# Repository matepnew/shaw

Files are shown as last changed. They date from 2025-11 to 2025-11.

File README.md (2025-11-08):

# SHAW!
Devboard based on the Blueprint guides to learn basics of electronics and PCB design.
 
## PCB
### Schematic


### PCB layout




### 3D Model




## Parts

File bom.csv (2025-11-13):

JLCPCB BOM Tool - BOM Matching
BOM name：bom-JLCPCB Assembly Order.xlsx |  |  | Download Time：2025-11-14 07:38:49 |  |  |  | * Our matching results are updated in real-time, but stock and prices may change. If it's been over 24 hours, please re-match before placing your order.
PCB Assembled Qty：5 |  |  | Est. Total Price：17.9448
Your BOM |  |  |  |  | Matched Parts |  |  |  |  |  |  | Order Information
Top Designator | Bottom Designator | Comment | Footprint | JLCPCB Part # | Matches | Part # | Manufacturer | Footprint | Description | Category | Warning | JLCPCB Part # | Product link | Lib Type | Qty | Source | Total Price ($)
C1,C12,C18 |  | 1uF | 0402 |  | Select by System | CL05A105KA5NQNC | Samsung Electro-Mechanics | 0402 | 1uF 25V X5R ±10% 0402 Multilayer Ceramic Capacitors MLCC - SMD/SMT ROHS | Multilayer Ceramic Capacitors MLCC - SMD/SMT |  | C52923 | https://jlcpcb.com/partdetail/53938-CL05A105KA5NQNC/C52923 | Basic | 15 | 15 JLCPCB | 0.0435
C10,C11,C17,C2,C3,C4,C5,C6,C7,C8,C9 |  | 0.1uF | 0402 |  | Unconfirmed | CL05B104KB54PNC | Samsung Electro-Mechanics | 0402 | 100nF 50V X7R ±10% 0402 Multilayer Ceramic Capacitors MLCC - SMD/SMT ROHS | Multilayer Ceramic Capacitors MLCC - SMD/SMT | 1.The comment (CL05B104KB54PNC) of this part does not match the one (0.1uF) provided in your BOM. Please confirm; | C307331 | https://jlcpcb.com/partdetail/291005-CL05B104KB54PNC/C307331 | Basic | 55 | 55 JLCPCB | 0.1925
C13,C14 |  | 10uF | 0603 |  | Select by System | CL10A106KP8NNNC | Samsung Electro-Mechanics | 0603 | 10V 10uF X5R ±10% 0603 Multilayer Ceramic Capacitors MLCC - SMD/SMT ROHS | Multilayer Ceramic Capacitors MLCC - SMD/SMT |  | C19702 | https://jlcpcb.com/partdetail/20411-CL10A106KP8NNNC/C19702 | Basic | 10 | 10 JLCPCB | 0.056
C15,C16 |  | 33pF | 0402 |  | Select by System | 0402CG330J500NT | FH (Guangdong Fenghua Advanced Tech) | 0402 | 33pF 50V C0G ±5% 0402 Multilayer Ceramic Capacitors MLCC - SMD/SMT ROHS | Multilayer Ceramic Capacitors MLCC - SMD/SMT |  | C1562 | https://jlcpcb.com/partdetail/1914-0402CG330J500NT/C1562 | Basic | 10 | 10 JLCPCB | 0.01
C19,C20 |  | 4.7uF | 0603 |  | Select by System | CL10A475KO8NNNC | Samsung Electro-Mechanics | 0603 | 16V 4.7uF X5R ±10% 0603 Multilayer Ceramic Capacitors MLCC - SMD/SMT ROHS | Multilayer Ceramic Capacitors MLCC - SMD/SMT |  | C19666 | https://jlcpcb.com/partdetail/20375-CL10A475KO8NNNC/C19666 | Basic | 10 | 10 JLCPCB | 0.092
D1,D2 |  | LED | 0402 |  | Unconfirmed | XL-1005UGC | XINGLIGHT | 0402 | -40℃~+85℃ 120° 249mcd 25mA 3V 516nm~531nm 531nm 80mW Emerald Green Water Clear op View Mount 0402 LED Indication - Discrete ROHS | LED Indication - Discrete | 1.The comment (XL-1005UGC) of this part does not match the one (LED) provided in your BOM. Please confirm; | C965793 | https://jlcpcb.com/partdetail/XINGLIGHT-XL1005UGC/C965793 | Extended | 22 | 22 JLCPCB | 0.1474
J1 |  | USB_C_Receptacle_USB2.0_14P | USB_C_Receptacle_HRO_TYPE-C-31-M-12 |  | Select by Customer | TYPE-C-31-M-12 | Korean Hroparts Elec | SMD | 1 16P 5A Female Type-C SMD USB Connectors ROHS | USB Connectors |  | C165948 | https://jlcpcb.com/partdetail/Korean_HropartsElec-TYPE_C_31_M12/C165948 | Extended | 5 | 5 JLCPCB | 0.847
J2,J3 |  | Conn_01x20 | PinHeader_1x20_P2.54mm_Vertical |  | Select by Customer | 2.54-1*20P直针 | BOOMELE(Boom Precision Elec) | 插件,P=2.54mm | -40℃~+105℃ 1 1x20P 2.54mm 20P 3A Black Brass Pin Header Through Hole Plugin,P=2.54mm Pin Headers ROHS | Pin Headers |  | C50981 | https://jlcpcb.com/partdetail/51993-2_54_1_20P/C50981 | Extended | 0 | 0 JLCPCB | 0
J4 |  | Conn_01x03 | PinHeader_1x03_P2.54mm_Vertical |  | Select by Customer | 2.54-1*3P针 | BOOMELE(Boom Precision Elec) | 插件,P=2.54mm | -40℃~+105℃ 1 1x3P 2.54mm 2.5mm 3A 3P 3mm 6mm Black Brass Gold Pin Header Through Hole Plugin,P=2.54mm Pin Headers ROHS | Pin Headers |  | C49257 | https://jlcpcb.com/partdetail/50265-2_54_1_3P/C49257 | Extended | 0 | 0 JLCPCB | 0
J5 |  | Conn_01x02 | JST_EH_B2B-EH-A_1x02_P2.50mm_Vertical |  | Select by Customer | B2B-EH-A(LF)(SN) | JST | 插件,P=2.5mm | -25℃~+85℃ 1 1x2P 2 2.5mm 250V 2P 3.8mm 3A 6mm 7.5mm Brass EH PA66 Through Hole Tin UL94V-0 White Plugin,P=2.5mm Wire To Board Connector ROHS | Wire To Board Connector |  | C160262 | https://jlcpcb.com/partdetail/JST-B2B_EH_A_LF_SN/C160262 | Extended | 9 | 9 JLCPCB | 0.3177
R1,R2 |  | 5.1K | 0402 |  | Unconfirmed | 0402WGF5101TCE | UNI-ROYAL(Uniroyal Elec) | 0402 | -55℃~+155℃ 5.1kΩ 50V 62.5mW Thick Film Resistor ±1% ±100ppm/℃ 0402 Chip Resistor - Surface Mount ROHS | Chip Resistor - Surface Mount | 1.The comment (0402WGF5101TCE) of this part does not match the one (5.1K) provided in your BOM. Please confirm; | C25905 | https://jlcpcb.com/partdetail/26648-0402WGF5101TCE/C25905 | Basic | 10 | 10 JLCPCB | 0.005
R3,R4 |  | 27 | 0402 |  | Unconfirmed | 0402WGF270JTCE | UNI-ROYAL(Uniroyal Elec) | 0402 | -55℃~+155℃ 27Ω 50V 62.5mW Thick Film Resistor ±1% ±100ppm/℃ 0402 Chip Resistor - Surface Mount ROHS | Chip Resistor - Surface Mount | 1.The comment (0402WGF270JTCE) of this part does not match the one (27) provided in your BOM. Please confirm; | C25100 | https://jlcpcb.com/partdetail/25843-0402WGF270JTCE/C25100 | Extended | 22 | 22 JLCPCB | 0.0132
R5,R7 |  | 1K | 0402 |  | Unconfirmed | 0402WGF1001TCE | UNI-ROYAL(Uniroyal Elec) | 0402 | -55℃~+155℃ 1kΩ 50V 62.5mW Thick Film Resistor ±1% ±100ppm/℃ 0402 Chip Resistor - Surface Mount ROHS | Chip Resistor - Surface Mount | 1.The comment (0402WGF1001TCE) of this part does not match the one (1K) provided in your BOM. Please confirm; | C11702 | https://jlcpcb.com/partdetail/12256-0402WGF1001TCE/C11702 | Basic | 10 | 10 JLCPCB | 0.006
R8,R9 |  | 1.5K | 0402 |  | Unconfirmed | 0402WGF1501TCE | UNI-ROYAL(Uniroyal Elec) | 0402 | -55℃~+155℃ 1.5kΩ 50V 62.5mW Thick Film Resistor ±1% ±100ppm/℃ 0402 Chip Resistor - Surface Mount ROHS | Chip Resistor - Surface Mount | 1.The comment (0402WGF1501TCE) of this part does not match the one (1.5K) provided in your BOM. Please confirm; | C25867 | https://jlcpcb.com/partdetail/26610-0402WGF1501TCE/C25867 | Basic | 10 | 10 JLCPCB | 0.006
R10 |  | 4.12K | 0402 |  | Unconfirmed | RC0402FR-074K12L | YAGEO | 0402 | -55℃~+155℃ 4.12kΩ 50V 62.5mW Thick Film Resistor ±1% ±100ppm/℃ 0402 Chip Resistor - Surface Mount ROHS | Chip Resistor - Surface Mount | 1.The comment (RC0402FR-074K12L) of this part does not match the one (4.12K) provided in your BOM. Please confirm; | C327340 | https://jlcpcb.com/partdetail/YAGEO-RC0402FR074K12L/C327340 | Extended | 20 | 20 JLCPCB | 0.006
R11 |  | 1.18K | 0402 |  | Unconfirmed | 0402WGF1181TCE | UNI-ROYAL(Uniroyal Elec) | 0402 | -55℃~+155℃ 1.18kΩ 50V 62.5mW Thick Film Resistor ±1% ±100ppm/℃ 0402 Chip Resistor - Surface Mount ROHS | Chip Resistor - Surface Mount | 1.The comment (0402WGF1181TCE) of this part does not match the one (1.18K) provided in your BOM. Please confirm; | C270651 | https://jlcpcb.com/partdetail/260031-0402WGF1181TCE/C270651 | Extended | 20 | 20 JLCPCB | 0.008
R12 |  | 1.13K | 0402 |  | Unconfirmed | 0402WGF1131TCE | UNI-ROYAL(Uniroyal Elec) | 0402 | -55℃~+155℃ 1.13kΩ 50V 62.5mW Thick Film Resistor ±1% ±100ppm/℃ 0402 Chip Resistor - Surface Mount ROHS | Chip Resistor - Surface Mount | 1.The comment (0402WGF1131TCE) of this part does not match the one (1.13K) provided in your BOM. Please confirm; | C67014 | https://jlcpcb.com/partdetail/68102-0402WGF1131TCE/C67014 | Extended | 20 | 20 JLCPCB | 0.012
R13,R6 |  | 10K | 0402 |  | Unconfirmed | 0402WGF1002TCE | UNI-ROYAL(Uniroyal Elec) | 0402 | -55℃~+155℃ 10kΩ 50V 62.5mW Thick Film Resistor ±1% ±100ppm/℃ 0402 Chip Resistor - Surface Mount ROHS | Chip Resistor - Surface Mount | 1.The comment (0402WGF1002TCE) of this part does not match the one (10K) provided in your BOM. Please confirm; | C25744 | https://jlcpcb.com/partdetail/26487-0402WGF1002TCE/C25744 | Basic | 10 | 10 JLCPCB | 0.006
SW1 |  | SW_Push | SW_Push_SPST_NO_Alps_SKRK |  | Select by Customer | TS-1088-AR02016 | XUNPU | SMD,4x3mm | -30℃~+80℃ 1.6N 100,000 Cycles 12V 2mm 3mm 4mm 50mA Black Round Button SMD(SMT) Tab SPST Surface Mount,Vertical Without Bracket SMD,4x3mm Tactile Switches ROHS | Tactile Switches |  | C720477 | https://jlcpcb.com/partdetail/XUNPU-TS_1088AR02016/C720477 | Basic | 5 | 5 JLCPCB | 0.2125
U1 |  | RP2040 | QFN-56-1EP_7x7mm_P0.4mm_EP3.2x3.2mm |  | Select by Customer | RP2040 | Raspberry Pi | LQFN-56(7x7) | 12bit 133MHz 30 LQFN-56(7x7) Microcontrollers (MCU/MPU/SOC) ROHS | Microcontrollers (MCU/MPU/SOC) |  | C2040 | https://jlcpcb.com/partdetail/RaspberryPi-RP2040/C2040 | Extended | 5 | 5 JLCPCB | 4.5825
U2 |  | MCP1700x-330xxTT | SOT-23 |  | Select by Customer | 2SA812(RANGE:300-400) | Jiangsu Changjing Electronics Technology Co., Ltd. | SOT-23 | -55℃~+150℃ 1 PNP 100mA 100nA 180MHz 200mW 300mV@100mA,10mA 50V 5V 90@1mA,6V PNP SOT-23 Bipolar (BJT) ROHS | Bipolar (BJT) |  | C2132 | https://jlcpcb.com/partdetail/2489-2SA812_RANGE_300_400/C2132 | Extended | 10 | 10 JLCPCB | 0.139
U3 |  | W25Q16JVSS | Winbond_USON-8-1EP_3x2mm_P0.5mm_EP0.2x1.6mm |  | Select by Customer | W25Q16JVUXIQ | Winbond Elec | USON-8-EP(2x3) | 100,000 Cycles 133MHz 16Mbit 2.7V~3.6V 20 Years 3ms SPI USON-8-EP(2x3) NOR FLASH ROHS | NOR FLASH | 1.The comment (W25Q16JVUXIQ) of this part does not match the one (W25Q16JVSS) provided in your BOM. Please confirm; | C2843335 | https://jlcpcb.com/partdetail/WinbondElec-W25Q16JVUXIQ/C2843335 | Extended | 5 | 5 JLCPCB | 3.2625
U4 |  | BQ24074RGT | VQFN-16-1EP_3x3mm_P0.5mm_EP1.6x1.6mm |  | Select by Customer | BQ24074RGTR | Texas Instruments | QFN-16-EP(3x3) | -40℃~+125℃ 1 1.5A 4.2V 4.35V~10.2V 6.5uA Charging IC Lithium Battery Support QFN-16-EP(3x3) Battery Management ROHS | Battery Management | 1.The comment (BQ24074RGTR) of this part does not match the one (BQ24074RGT) provided in your BOM. Please confirm; | C54313 | https://jlcpcb.com/partdetail/TexasInstruments-BQ24074RGTR/C54313 | Extended | 5 | 5 JLCPCB | 6.0075
Y1 |  | 12MHz | Crystal_SMD_3225-4Pin_3.2x2.5mm |  | Unconfirmed | DSX321G 12MHz | KDS Daishinku | SMD3225-4P | SMD3225-4P Crystals ROHS | Crystals | 1.The comment (DSX321G 12MHz) of this part does not match the one (12MHz) provided in your BOM. Please confirm; | C93234 | https://jlcpcb.com/partdetail/KDSDaishinku-DSX321G12MHz/C93234 | Extended | 5 | 5 JLCPCB | 1.9725

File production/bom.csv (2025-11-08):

Designator | Footprint | Quantity | Value | LCSC Part #
C1, C12, C18 | 0402 | 3 | 1uF
C10, C11, C17, C2, C3, C4, C5, C6, C7, C8, C9 | 0402 | 11 | 0.1uF
C13, C14 | 0603 | 2 | 10uF
C15, C16 | 0402 | 2 | 33pF
C19 | 0603 | 1 | 4.7uF
C20 | 0201 | 1 | 4.7uF
D1, D2 | 0402 | 2 | LED
J1 | USB_C_Receptacle_HRO_TYPE-C-31-M-12 | 1 | USB_C_Receptacle_USB2.0_14P
J2, J3 | PinHeader_1x20_P2.54mm_Vertical | 2 | Conn_01x20
J4 | PinHeader_1x03_P2.54mm_Vertical | 1 | Conn_01x03
J5 | JST_EH_B2B-EH-A_1x02_P2.50mm_Vertical | 1 | Conn_01x02
R1, R2 | 0402 | 2 | 5.1K
R10 | 0402 | 1 | 4.12K
R11 | 0402 | 1 | 1.18K
R12 | 0402 | 1 | 1.13K
R13, R6 | 0402 | 2 | 10K
R3, R4 | 0402 | 2 | 27
R5, R7 | 0402 | 2 | 1K
R8, R9 | 0402 | 2 | 1.5K
SW1 | SW_Push_SPST_NO_Alps_SKRK | 1 | SW_Push
U1 | QFN-56-1EP_7x7mm_P0.4mm_EP3.2x3.2mm | 1 | RP2040
U2 | SOT-23 | 1 | MCP1700x-330xxTT
U3 | Winbond_USON-8-1EP_3x2mm_P0.5mm_EP0.2x1.6mm | 1 | W25Q16JVSS
U4 | VQFN-16-1EP_3x3mm_P0.5mm_EP1.6x1.6mm | 1 | BQ24074RGT
Y1 | Crystal_SMD_3225-4Pin_3.2x2.5mm | 1 | 12MHz

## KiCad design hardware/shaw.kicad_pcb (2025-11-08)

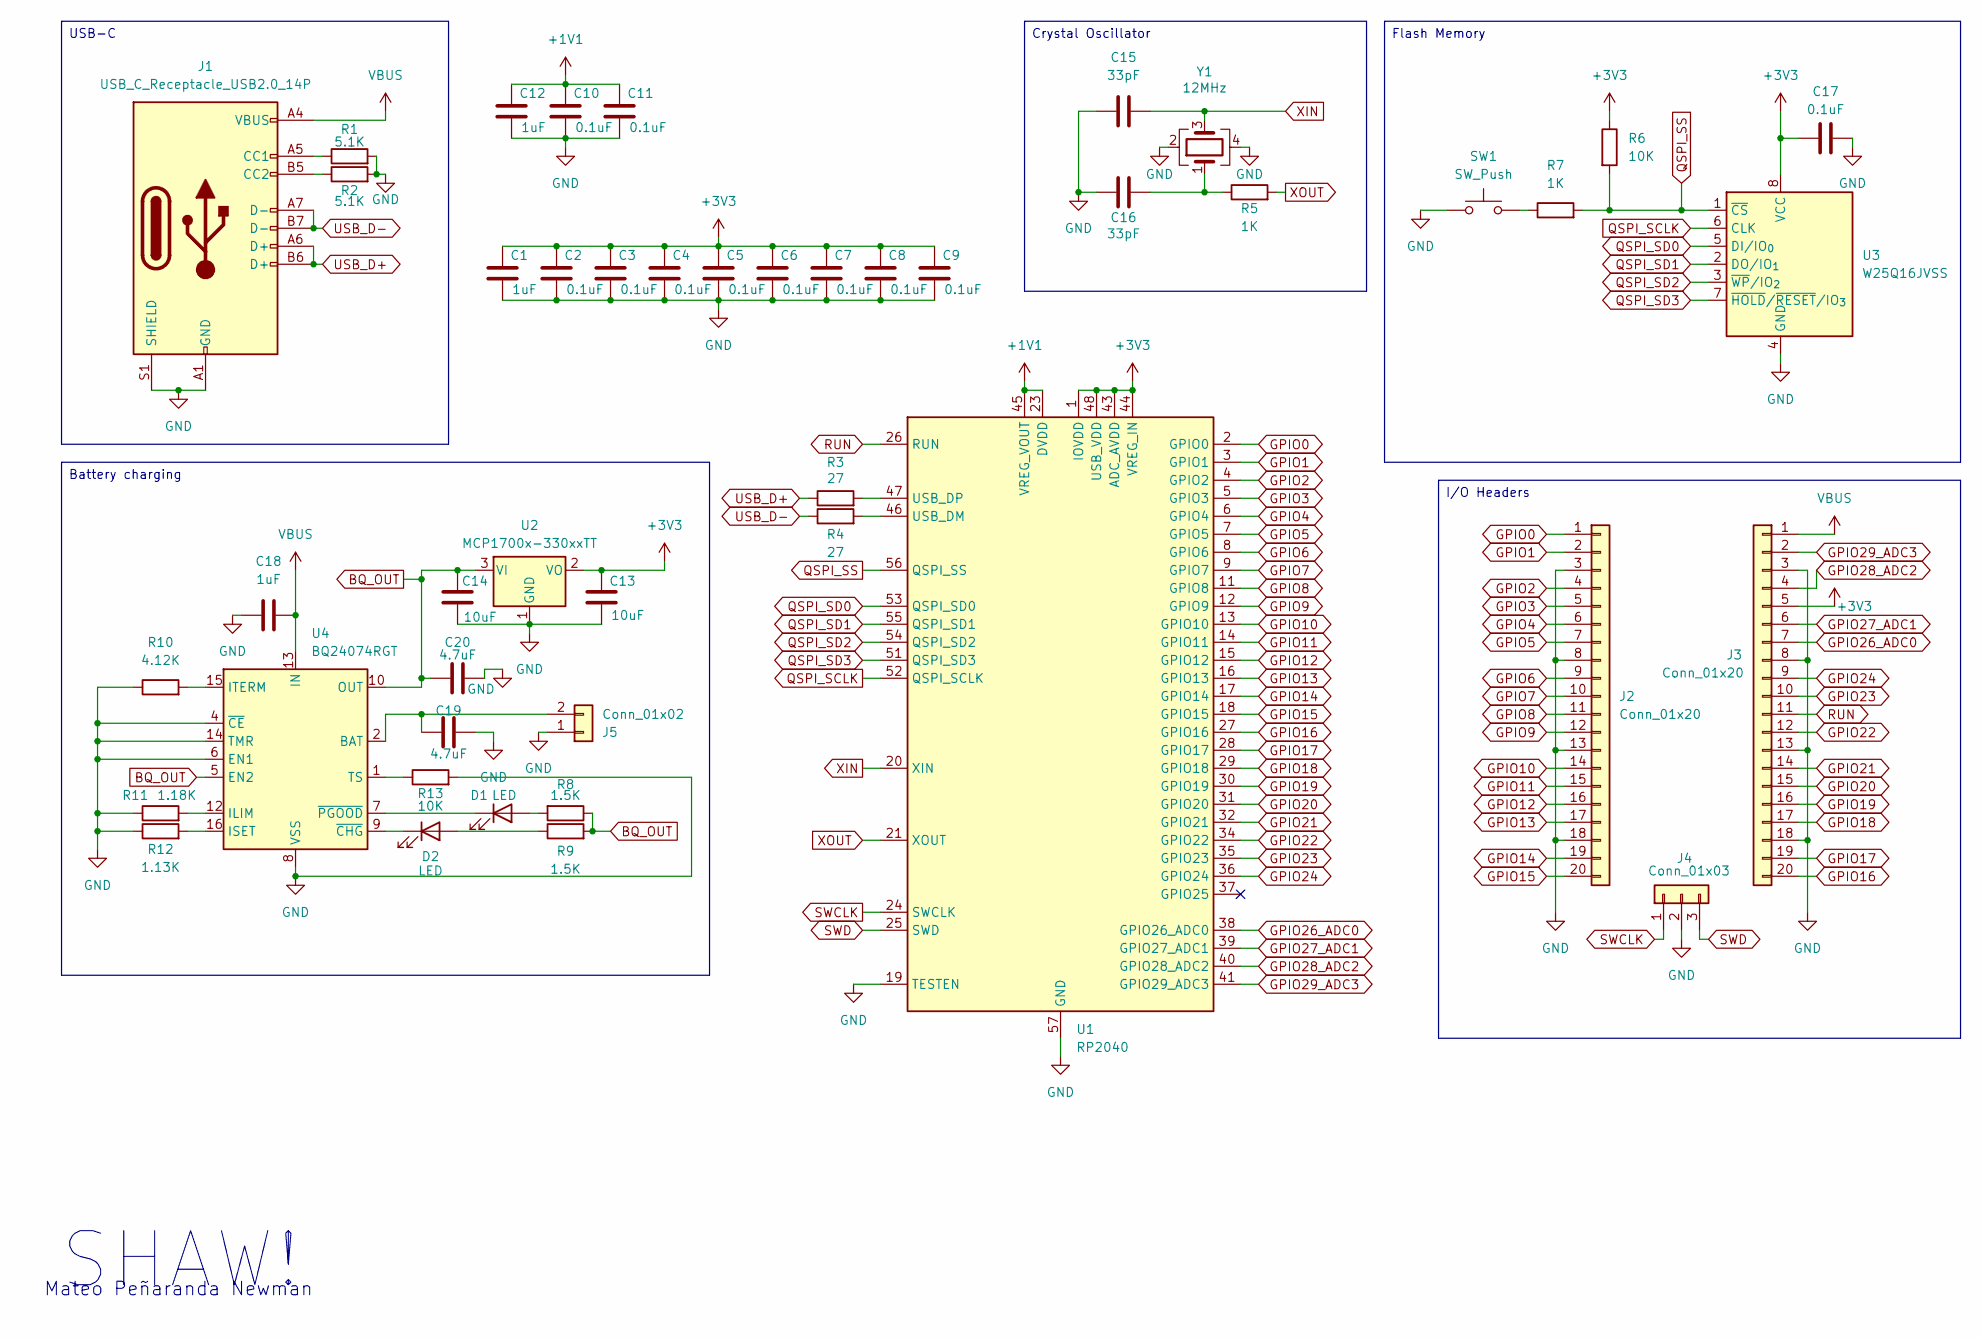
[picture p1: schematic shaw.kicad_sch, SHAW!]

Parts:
C1, C12, C18: 1uF; C_0402_1005Metric
C2, C3, C4, C5, C6, C7, C8, C9, C10, C11, C17: 0.1uF; C_0402_1005Metric
C13, C14: 10uF; C_0603_1608Metric
C15, C16: 33pF; C_0402_1005Metric
C19, C20: 4.7uF; C_0603_1608Metric
D1, D2: LED; LED_0402_1005Metric
J1: USB_C_Receptacle_USB2.0_14P; USB_C_Receptacle_HRO_TYPE-C-31-M-12
J2, J3: Conn_01x20; PinHeader_1x20_P2.54mm_Vertical
J4: Conn_01x03; PinHeader_1x03_P2.54mm_Vertical
J5: Conn_01x02; JST_EH_B2B-EH-A_1x02_P2.50mm_Vertical
R1, R2: 5.1K; R_0402_1005Metric
R3, R4: 27; R_0402_1005Metric
R5, R7: 1K; R_0402_1005Metric
R6, R13: 10K; R_0402_1005Metric
R8, R9: 1.5K; R_0402_1005Metric
R10: 4.12K; R_0402_1005Metric
R11: 1.18K; R_0402_1005Metric
R12: 1.13K; R_0402_1005Metric
SW1: SW_Push; SW_Push_SPST_NO_Alps_SKRK
U1: RP2040; QFN-56-1EP_7x7mm_P0.4mm_EP3.2x3.2mm
U2: MCP1700x-330xxTT; SOT-23
U3: W25Q16JVSS; Winbond_USON-8-1EP_3x2mm_P0.5mm_EP0.2x1.6mm
U4: BQ24074RGT; VQFN-16-1EP_3x3mm_P0.5mm_EP1.6x1.6mm
Y1: 12MHz; Crystal_SMD_3225-4Pin_3.2x2.5mm

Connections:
+1V1: C10.1, C11.1, C12.1, U1.23 (DVDD), U1.45 (VREG_VOUT), U1.50 (DVDD)
+3V3: C1.1, C2.1, C3.1, C4.1, C5.1, C6.1, C7.1, C8.1, C9.1, C13.1, C17.1, J3.5, R6.1, U1.1 (IOVDD), U1.10 (IOVDD), U1.22 (IOVDD), U1.33 (IOVDD), U1.42 (IOVDD), U1.43 (ADC_AVDD), U1.44 (VREG_IN), U1.48 (USB_VDD), U1.49 (IOVDD), U2.2 (VO), U3.8 (VCC)
BQ_OUT: C14.1, C20.1, R8.1, R9.2, U2.3 (VI), U4.5 (EN2), U4.10 (OUT), U4.11 (OUT)
GND: C1.2, C2.2, C3.2, C4.2, C5.2, C6.2, C7.2, C8.2, C9.2, C10.2, C11.2, C12.2, C13.2, C14.2, C15.1, C16.2, C17.2, C18.1, C19.2, C20.2, J1.A1 (GND), J1.A12 (GND), J1.B1 (GND), J1.B12 (GND), J1.S1 (SHIELD), J2.3, J2.8, J2.13, J2.18, J3.3, J3.8, J3.13, J3.18, J4.2, J5.1, R1.2, R2.2, R10.1, R11.1, R12.1, R13.2, SW1.1, U1.19 (TESTEN), U1.57 (GND), U2.1 (GND), U3.4 (GND), U4.4 (~CE), U4.6 (EN1), U4.8 (VSS), U4.14 (TMR), U4.17 (VSS), Y1.2, Y1.4
GPIO0: J2.1, U1.2 (GPIO0)
GPIO1: J2.2, U1.3 (GPIO1)
GPIO2: J2.4, U1.4 (GPIO2)
GPIO3: J2.5, U1.5 (GPIO3)
GPIO4: J2.6, U1.6 (GPIO4)
GPIO5: J2.7, U1.7 (GPIO5)
GPIO6: J2.9, U1.8 (GPIO6)
GPIO7: J2.10, U1.9 (GPIO7)
GPIO8: J2.11, U1.11 (GPIO8)
GPIO9: J2.12, U1.12 (GPIO9)
GPIO10: J2.14, U1.13 (GPIO10)
GPIO11: J2.15, U1.14 (GPIO11)
GPIO12: J2.16, U1.15 (GPIO12)
GPIO13: J2.17, U1.16 (GPIO13)
GPIO14: J2.19, U1.17 (GPIO14)
GPIO15: J2.20, U1.18 (GPIO15)
GPIO16: J3.20, U1.27 (GPIO16)
GPIO17: J3.19, U1.28 (GPIO17)
GPIO18: J3.17, U1.29 (GPIO18)
GPIO19: J3.16, U1.30 (GPIO19)
GPIO20: J3.15, U1.31 (GPIO20)
GPIO21: J3.14, U1.32 (GPIO21)
GPIO22: J3.12, U1.34 (GPIO22)
GPIO23: J3.10, U1.35 (GPIO23)
GPIO24: J3.9, U1.36 (GPIO24)
GPIO26_ADC0: J3.7, U1.38 (GPIO26_ADC0)
GPIO27_ADC1: J3.6, U1.39 (GPIO27_ADC1)
GPIO28_ADC2: J3.4, U1.40 (GPIO28_ADC2)
GPIO29_ADC3: J3.2, U1.41 (GPIO29_ADC3)
unnamed: C16.1, R5.1, Y1.1
unnamed: D1.2 (A), R8.2
unnamed: D1.1 (K), U4.7 (~PGOOD)
unnamed: D2.2 (A), R9.1
unnamed: D2.1 (K), U4.9 (~CHG)
unnamed: J1.A5 (CC1), R1.1
unnamed: J1.B5 (CC2), R2.1
unnamed: C19.1, J5.2, U4.2 (BAT), U4.3 (BAT)
unnamed: R7.1, SW1.2
unnamed: R4.2, U1.46 (USB_DM)
unnamed: R3.2, U1.47 (USB_DP)
unnamed: R11.2, U4.12 (ILIM)
unnamed: R12.2, U4.16 (ISET)
unnamed: R10.2, U4.15 (ITERM)
unnamed: R13.1, U4.1 (TS)
QSPI_SCLK: U1.52 (QSPI_SCLK), U3.6 (CLK)
QSPI_SD0: U1.53 (QSPI_SD0), U3.5 (DI/IO_{0})
QSPI_SD1: U1.55 (QSPI_SD1), U3.2 (DO/IO_{1})
QSPI_SD2: U1.54 (QSPI_SD2), U3.3 (~WP/IO_{2})
QSPI_SD3: U1.51 (QSPI_SD3), U3.7 (~HOLD/~RESET/IO_{3})
QSPI_SS: R6.2, R7.2, U1.56 (QSPI_SS), U3.1 (~CS)
RUN: J3.11, U1.26 (RUN)
SWCLK: J4.1, U1.24 (SWCLK)
SWD: J4.3, U1.25 (SWD)
USB_D+: J1.A6 (D+), J1.B6 (D+), R3.1
USB_D-: J1.A7 (D-), J1.B7 (D-), R4.1
VBUS: C18.2, J1.A4 (VBUS), J1.A9 (VBUS), J1.B4 (VBUS), J1.B9 (VBUS), J3.1, U4.13 (IN)
XIN: C15.2, U1.20 (XIN), Y1.3
XOUT: R5.2, U1.21 (XOUT)

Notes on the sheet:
SHAW!
Mateo Peñaranda Newman
Flash Memory
USB-C
Battery charging
Crystal Oscillator
I/O Headers

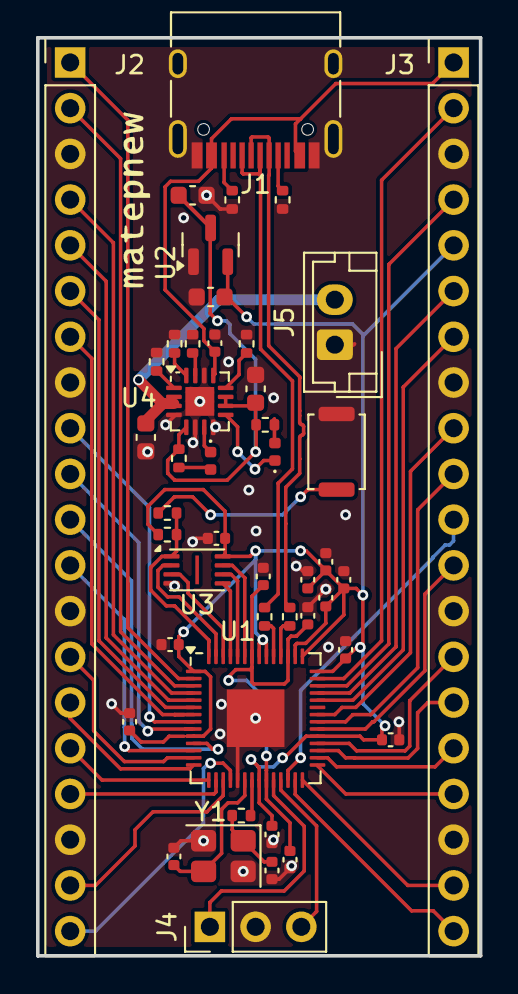
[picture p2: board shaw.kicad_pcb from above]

Board: 2 copper layers, 24.6 x 51.0 mm, 46 parts (0 on the bottom side), 62 nets.

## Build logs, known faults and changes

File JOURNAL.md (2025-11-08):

<!--
  ===================    !!READ THIS NOTICE!!   ====================
  DO NOT edit this file manually. Your changes WILL BE OVERWRITTEN!
  This journal is auto generated and updated by Hack Club Blueprint.
  To edit this file, please edit your journal entries on Blueprint.
  ==================================================================
-->

## 10/8/2025 - Made schematic  

Started by following the guide; added capacitors to power lines, USB-C and its voltage regulator, crystal oscillator, flash memory and I/O headers. Also researched a bit about decoupling capacitors and piezoelectricity (very cool). Planning to maybe add support for a battery and start making the PCB tomorrow. 



## 10/9/2025 - Added battery charging  

I added support for battery charging with a Texas Instrument BQ24074 chip to make the devboard more versatile. Also rearranged the schematic to add space for said battery charger without having to expand the schematic and added a nice title. Will take a silksong break and afterwards start making the PCB.



## 10/12/2025 - Started work on the PCB  

With the schematics done, I started reading the guide's section on the PCB. As such, I started by adding the footprints for each component. As I entered the PCB editor, I noticed there were a few minor errors in the schematic, which I fixed. Afterwards, I placed the header pins, RP2040, USB receptacle, crystal oscillator and decoupling capacitors following the guide. Also began routing the PCB, though I'm still missing most of it. Planning on finding a spot for the battery charger and finishing the PCB soon so I can start working on the other projects I have in mind.





## 10/28/2025 - PCB work  

While working on and off due to other stuff, I added all remaining components to the PCB and routed them. I expanded the PCB a bit to make way for the GPIO tracks, as the components for the battery take up quite a bit of space. Even with the extra space, it was a bit hard to route GPIOs (and everything else to the RP2040 really). Next up, I'll make sure to fix any mistakes, and clean up the silkscreen.



## 11/8/2025 - Final touches  

Fixed the errors that showed up when I ran the DRC, mostly clearance issues and a couple of missing ground connections. After that, I added a little hornet to the silkscreen (I named this project shaw because it was the first thing that came to mind when I started, as I was playing multiple hours of Silksong every day) and my username. Finally, I touched up the README a bit to be able to ship the project.

Here's the (hopefully) final PCB layout


And the 3D model


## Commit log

2025-11-08 Update README with PCB details and images
    Added PCB schematic, layout, and 3D model images.
2025-11-09 update bom
    [BOM.csv]
2025-11-13 Replace bom
    [bom.csv]
